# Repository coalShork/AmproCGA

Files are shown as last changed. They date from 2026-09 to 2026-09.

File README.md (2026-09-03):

# AmproCGA
A CGA card for the Ampro Little Board PC. Takes CPLDs from a generic Chinese CGA card for compactness.

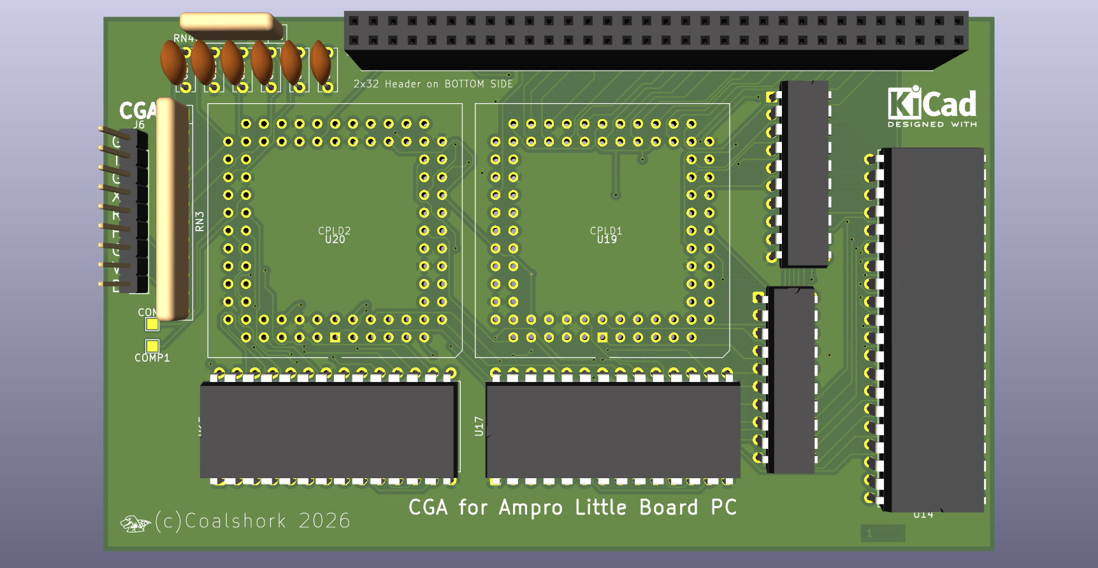
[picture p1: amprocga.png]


The CPLDs used in this are from [this card.](https://8086cpu.com/lm6/79.html) 
If you intend to build one you will need to purchase that card from eBay or something and transfer the ICs to my board.
As of writing this, the board has not been tested, do not expect it to work first try. I expect there will be some hiccups.

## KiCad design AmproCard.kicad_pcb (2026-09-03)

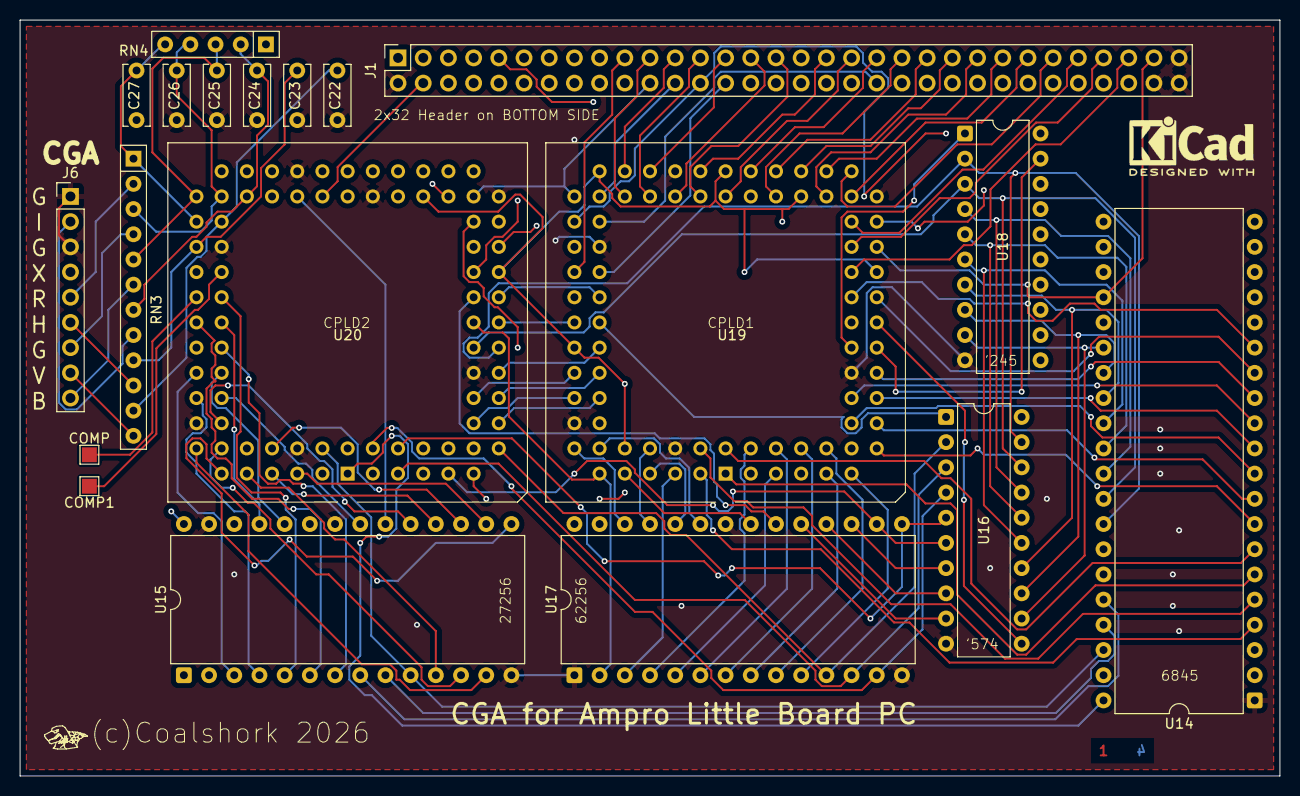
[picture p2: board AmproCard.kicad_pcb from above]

Board: 4 copper layers, 127.0 x 76.2 mm, 20 parts (0 on the bottom side), 136 nets.

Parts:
C22, C23, C24, C25, C26, C27: 47pF; C_Disc_D6.0mm_W2.5mm_P5.00mm
COMP, COMP1: TestPoint_Pad_1.5x1.5mm
CoalLogo: Val**; CoalLogo
J1: Conn_02x32_Odd_Even; PinSocket_2x32_P2.54mm_Vertical
J6: CGA; PinHeader_1x09_P2.54mm_Vertical
RN3: 33; R_Array_SIP12
RN4: 4.7K; R_Array_SIP5
U14: MC6845; DIP-40_W15.24mm
U15: 27C256; DIP-28_W15.24mm
U16: 74LS574; DIP-20_W7.62mm
U17: KM62256CLP; DIP-28_W15.24mm
U18: 74HC245; DIP-20_W7.62mm
U19, U20: CGA CPLD 1; PLCC-84_THT-Socket

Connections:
6845-CS: U14.25 (~CS), U19.30 (6845CS)
6845-E: U14.23 (E), U19.23 (6845-E)
+5V: J1.6, J1.58, RN4.1 (common), U14.20 (VCC), U15.2 (A12), U15.23 (A11), U15.28 (VCC), U16.20 (VCC), U17.28 (VCC), U18.20 (VCC), U19.3 (VCC), U19.13 (VCC), U19.26 (VCC), U19.38 (VCC), U19.43 (VCC), U19.53 (VCC), U19.66 (VCC), U19.78 (VCC), U20.3 (VCC), U20.13 (VCC), U20.26 (VCC), U20.38 (VCC), U20.43 (VCC), U20.53 (VCC), U20.66 (VCC), U20.78 (VCC)
A0: J1.61, U14.24 (RS), U19.28 (A0)
A1: J1.59, U19.27 (A1)
A2: J1.57, U19.29 (A2)
A3: J1.55, U19.31 (A3)
A4: J1.53, U19.33 (A4)
A5: J1.51, U19.34 (A5)
A6: J1.49, U19.35 (A6)
A7: J1.47, U19.36 (A7)
A8: J1.45, U19.37 (A8)
A9: J1.43, U19.39 (A9)
A10: J1.41, U19.40 (A10)
A11: J1.39, U19.41 (A11)
A12: J1.37, U19.44 (A12)
A13: J1.35, U19.45 (A13)
A15: J1.31, U19.46 (A15)
A16: J1.29, U19.48 (A16)
A17: J1.27, U19.49 (A17)
A18: J1.25, U19.50 (A18)
A19: J1.23, U19.51 (A19)
AEN: J1.21, U19.52 (AEN)
BLUE: C25.1, RN3.5 (R3.1), RN4.3 (R2), U20.54 (B)
CA0: U14.4 (MA0), U19.83 (CRTMA0)
CA1: U14.5 (MA1), U19.84 (CRTMA1)
CA2: U14.6 (MA2), U19.1 (CRTMA2)
CA3: U14.7 (MA3), U19.2 (CRTMA3)
CA4: U14.8 (MA4), U19.12 (CRTMA4)
CA5: U14.9 (MA5), U19.14 (CRTMA5)
CA6: U14.10 (MA6), U19.15 (CRTMA6)
CA7: U14.11 (MA7), U19.16 (CRTMA7)
CA8: U14.12 (MA8), U19.17 (CRTMA8)
CA9: U14.13 (MA9), U19.18 (CRTMA9)
CA10: U14.14 (MA10), U19.24 (CRTMA10)
CA11: U14.15 (MA11), U19.25 (CRTMA11)
CA12: U14.16 (MA12), U20.37 (CRTMA12)
CBLUE: J6.9, RN3.6 (R3.2)
CC0: U15.7 (A3), U20.67 (CC0)
CC1: U15.6 (A4), U20.64 (CC1)
CC2: U15.5 (A5), U20.63 (CC2)
CC3: U15.4 (A6), U20.70 (CC3)
CC4: U15.3 (A7), U20.68 (CC4)
CC5: U15.25 (A8), U20.65 (CC5)
CC6: U15.24 (A9), U20.69 (CC6)
CC7: U15.21 (A10), U20.71 (CC7)
CCLK: U14.21 (CLK), U20.40 (CCLK)
CGREEN: J6.7, RN3.4 (R2.2)
CHSYNC: J6.6, RN3.10 (R5.2)
CINTENSITY: J6.2, RN3.8 (R4.2)
CLK: J1.40, U19.57 (IOCLK)
COMP: COMP.1, U20.62 (COMP-OUT)
COMP1: COMP1.1, U20.61 (COMP-OUT151)
CRED: J6.5, RN3.2 (R1.2)
CURSOR: U14.19 (CURSOR), U20.28 (CURSOR)
CVSYNC: J6.8, RN3.12 (R6.2)
D0: J1.17, U18.18 (B0)
D1: J1.15, U18.17 (B1)
D2: J1.13, U18.16 (B2)
D3: J1.11, U18.15 (B3)
D4: J1.9, U18.14 (B4)
D5: J1.7, U18.13 (B5)
D6: J1.5, U18.12 (B6)
D7: J1.3, U18.11 (B7)
DATA-DIR: U18.1 (A->B), U19.21 (DATADIR)
DATA-GATE: U18.19 (CE), U19.20 (DATAGATE)
DB0: U14.33 (D0), U16.19 (Q0), U18.2 (A0), U20.20 (DB0)
DB1: U14.32 (D1), U16.18 (Q1), U18.3 (A1), U20.21 (DB1)
DB2: U14.31 (D2), U16.17 (Q2), U18.4 (A2), U20.27 (DB2)
DB3: U14.30 (D3), U16.16 (Q3), U18.5 (A3), U20.29 (DB3)
DB4: U14.29 (D4), U16.15 (Q4), U18.6 (A4), U20.30 (DB4)
DB5: U14.28 (D5), U16.14 (Q5), U18.7 (A5), U20.35 (DB5)
DB6: U14.27 (D6), U16.13 (Q6), U18.8 (A6), U20.33 (DB6)
DB7: U14.26 (D7), U16.12 (Q7), U18.9 (A7), U20.36 (DB7)
DISPEN: U14.18 (DE), U20.31 (DISPEN)
DOT0: U15.11 (D0), U20.77 (DOT0)
DOT1: U15.12 (D1), U20.76 (DOT1)
DOT2: U15.13 (D2), U20.74 (DOT2)
DOT3: U15.15 (D3), U20.75 (DOT3)
DOT4: U15.16 (D4), U20.81 (DOT4)
DOT5: U15.17 (D5), U20.80 (DOT5)
DOT6: U15.18 (D6), U20.79 (DOT6)
DOT7: U15.19 (D7), U20.73 (DOT7)
ENCPUADDR: U19.67 (ENCPUADD), U20.18 (EN-CPU-ADDR)
GND: C22.2, C23.2, C24.2, C25.2, C26.2, C27.2, J1.2, J1.20, J1.62, J1.63, J1.64, J6.1, J6.3, U14.1 (GND), U15.14 (GND), U15.22 (~OE), U15.26 (A13), U15.27 (A14), U16.10 (GND), U17.1 (A14), U17.14 (GND), U17.22 (~OE), U18.10 (GND), U19.7 (GND), U19.19 (GND), U19.32 (GND), U19.42 (GND), U19.47 (GND), U19.59 (GND), U19.72 (GND), U19.82 (GND), U20.7 (GND), U20.19 (GND), U20.32 (GND), U20.42 (GND), U20.47 (GND), U20.59 (GND), U20.72 (GND), U20.82 (GND)
GREEN: C26.1, RN3.3 (R2.1), RN4.4 (R3), U20.55 (G)
HSYNC: U14.39 (HS), U20.2 (VSYNC)
HSYNC1: C23.1, RN3.9 (R5.1), U20.58 (HSYNC-O1)
INTENSITY: C24.1, RN3.7 (R4.1), RN4.2 (R1), U20.52
IOR: J1.28, U19.61 (IOR#)
IOW: J1.26, U14.22 (R/~W), U19.56 (IOW)
I/OCHRDY: J1.19, U19.60 (IOREADY)
MD0: U16.2 (D0), U17.11 (Q0), U20.12 (MD0)
MD1: U16.3 (D1), U17.12 (Q1), U20.5 (MD1)
MD2: U16.4 (D2), U17.13 (Q2), U20.4 (MD2)
MD3: U16.5 (D3), U17.15 (Q3), U20.6 (MD3)
MD4: U16.6 (D4), U17.16 (Q4), U20.9 (MD4)
MD5: U16.7 (D5), U17.17 (Q5), U20.11 (MD5)
MD6: U16.8 (D6), U17.18 (Q6), U20.8 (MD6)
MD7: U16.9 (D7), U17.19 (Q7), U20.10 (MD7)
MEMR: J1.24, U19.55 (MEMR)
MEMW: J1.22, U19.54 (MEMW), U20.34 (MEMW)
unnamed: U19.70 (MA12OUT), U20.15 (MA12OUT)
unnamed: U19.71 (Q1), U20.14 (O1)
unnamed: U19.68 (SEL1), U20.17 (SEL1)
unnamed: U19.69 (SEL2), U20.16 (SEL2)
unnamed: U19.63 (STATSEL), U20.24 (STATSEL)
OSC: J1.60, U20.39 (OSC)
RA0: U14.38 (RA0), U15.10 (A0), U20.84 (RA0)
RA1: U14.37 (RA1), U15.9 (A1)
RA2: U14.36 (RA2), U15.8 (A2)
RAMA0: U17.10 (A0), U19.11 (RAMA0)
RAMA1: U17.9 (A1), U19.10 (RAMA1)
RAMA2: U17.8 (A2), U19.9 (RAMA2)
RAMA3: U17.7 (A3), U19.8 (RAMA3)
RAMA4: U17.6 (A4), U19.6 (RAMA4)
RAMA5: U17.5 (A5), U19.5 (RAMA5)
RAMA6: U17.4 (A6), U19.4 (RAMA6)
RAMA7: U17.3 (A7), U19.81 (RAMA7)
RAMA8: U17.25 (A8), U19.80 (RAMA8)
RAMA9: U17.24 (A9), U19.79 (RAMA9)
RAMA10: U17.21 (A10), U19.77 (RAMA10)
RAMA11: U17.23 (A11), U19.76 (RAMA11)
RAMA12: U17.2 (A12), U19.75 (RAMA12), U20.23 (RAM-A12)
RAMA13: U17.26 (A13), U19.74 (RAMA13)
RCS: U17.20 (~CS), U20.25 (RAMCS)
RD-GATE: U16.1 (OE), U19.65 (RDGATE)
RED: C27.1, RN3.1 (R1.1), RN4.5 (R4), U20.56 (R)
RESET: J1.4, U20.46 (~RESET)
ROMCS: U15.20 (~CE), U20.48 (ROMCS)
RWE: U17.27 (~WE), U20.41 (WE)
U2-6: U19.64 (U2-6), U20.22 (U2-6)
VSYNC: U14.40 (VS), U20.1 (HSYNC)
VSYNC1: C22.1, RN3.11 (R6.1), U20.57 (VSYNC-O1)
XACK: U16.11 (Cp), U19.22 (XACK)
~RAS: U19.73 (RAS), U20.45 (RAS)
